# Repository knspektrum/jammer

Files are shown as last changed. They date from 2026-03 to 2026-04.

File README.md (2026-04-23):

# jammer

Milestones:
2026-04 - Finish research and ensure that everyone understands it.
2026-05 - Simulate core components. Complete simulation of both hardware and software (modulation/demodulation).
2026-06 - Order parts for the prototype like FPGA devboards.
2026-07 - Complete the prototype and develop software to jam things supported by the NRF jammer, implement signal reception and decoding.
2026-08 - Design the final PCB and place the order.

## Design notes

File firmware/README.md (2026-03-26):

NRF24L01+PA+LNA jammer for 2.4GHz band.

This project aims to create a jammer for devices operating in the [https://en.wikipedia.org/wiki/2.4_GHz_radio_use](2.4GHz band).

### Wiring
Check config.h. Currently we use 2 NRF modules, an SSD1306-compatible display (I2C), and 3 buttons for navigation.

### Theoretical basis
The NRF works on 2400-2525MHz frequencies. 1 channel = 1 MHz and there are 125 channels.

We can choose TX power and speed. Bandwidth depends on speed.
TX power: -18dBm, -12dBm, -6dBm, 0dBm
Speed: 1Mbps, 2Mbps, 250Kbps
Bandwidth: 1MHz or 2MHz

[https://docs.nordicsemi.com/bundle/nRF24L01P_PS_v1.0/resource/nRF24L01P_PS_v1.0.pdf](https://docs.nordicsemi.com/bundle/nRF24L01P_PS_v1.0/resource/nRF24L01P_PS_v1.0.pdf)

The status of RPD is correct when RX after an appropriate delay:
Tstby2a +Tdelay_AGC= 130us + 40us. RPD is used to detect activity on a band.

The RF channel frequency determines the center of the channel used by the nRF24L01+. The channel
occupies a bandwidth of less than 1MHz at 250kbps and 1Mbps and a bandwidth of less than 2MHz at
2Mbps. nRF24L01+ can operate on frequencies from 2.400GHz to 2.525GHz. The programming resolu-
tion of the RF channel frequency setting is 1MHz

build, upload and monitor:
make upload-release monitor

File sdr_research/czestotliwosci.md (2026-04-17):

# Częstotliwości

> Musimy doprecyzować jaki przedział częstotliwości nas interesuje, proponuję coś koło 20MHz-6GHz

125 kHz - jedna z częstotliwości RFID, zagłuszanie średnio ma sens ale można reply ataki robić i po prostu czytać dane
77.5 kHz - zegary atomowe, zagłuszanie może popsuć niektóre urządzenia które synchronizują się z nim, potencjlanie też można spoofować

13.56 MHz - kolejna częstotliwość RFID, tutaj wszystkie karty do hoteli, karty płatnicze, potencjlanie odczytywanie danych z nich
27 MHz - CB radio

87,5 do 108,0 MHz - pasmo dla radia FM, można zagłuszyć i nadawać swoje
108 – 137 MHz - pasma samolotów, można wyczytać lokalizacje
144.800 MHz - APRS, ludzie amatorsko reportują lokalizacje różnych obiektów, czasem ludzie tu wysyłają pogode albo wiadomości tekstowe
150.000 – 150.450 MHz - PKP tu nadaje, nieszyfrowana komunikacja, https://czestotliwosci.pl.tl/PKP.htm
161.975 / 162.025 - AIS, można słuchać gdzie statki pływają

433 MHz - legalne pasmo bez licencji, piloty do bram, kluczyki do samochodu
446,000 – 446,200 MHz - PMRy, "walkie talkie" ale używane też np na basenach przez ratowników
865–868 MHz - UHF RFID, używane w logistyce, jakieś paczki w magazynach
868 MHz - legalne pasmo, całe IoT z tego korzyta np lora. inteligentne liczniki gazu, prądu, wody, bezprzewodowe dzwonki
700 MHz – 2.6 GHz - całe GSM https://pl.wikipedia.org/wiki/Cz%C4%99stotliwo%C5%9Bci_u%C5%BCywane_w_sieci_GSM, obszerny temat
1575.42 MHz - GPS, da się spoofować
gnss - to całe pasmo do pozycji z satelit, dużo kraji ma swoje altenatywy do amerykańskiego GPS, Galileo OSNMA podpisuje swoje wiadomosci, uniemozliwia spoofowanie
2.4Ghz - wiadomo BT, BLE, WiFi, Zigbee, niektóre drony
5GHz, do 5875 MHz dokładnie - Kolejne pasmo wifi
5-6Ghz - FPV drony, https://oscarliang.com/fpv-channels/

Telewizja naziemna:
UHF (470-694 MHz, kanały 21-48) oraz VHF (174-230 MHz, kanały 6-12 dla MUX 8).

Około 145Mhz jest pasmo ISS (Międzynarodowa Stacja Kosmiczna)

Pasma SSTV, wysyłanie obrazów amatorsko:
3,735 MHz (3,730 MHz – 3,740 MHz)       LSB
7,165 MHz (7,035 MHz – 7,045 MHz)       LSB
14,230 MHz (14,225 MHz – 14,235 MHz)    USB
21,340 MHz (21,335 MHz – 21,345 MHz)    USB
28,680 MHz (28,675 MHz – 28,685 MHz)    USB
50,510 MHz      FM
144,500 MHz     FM
433,400 MHz     FM

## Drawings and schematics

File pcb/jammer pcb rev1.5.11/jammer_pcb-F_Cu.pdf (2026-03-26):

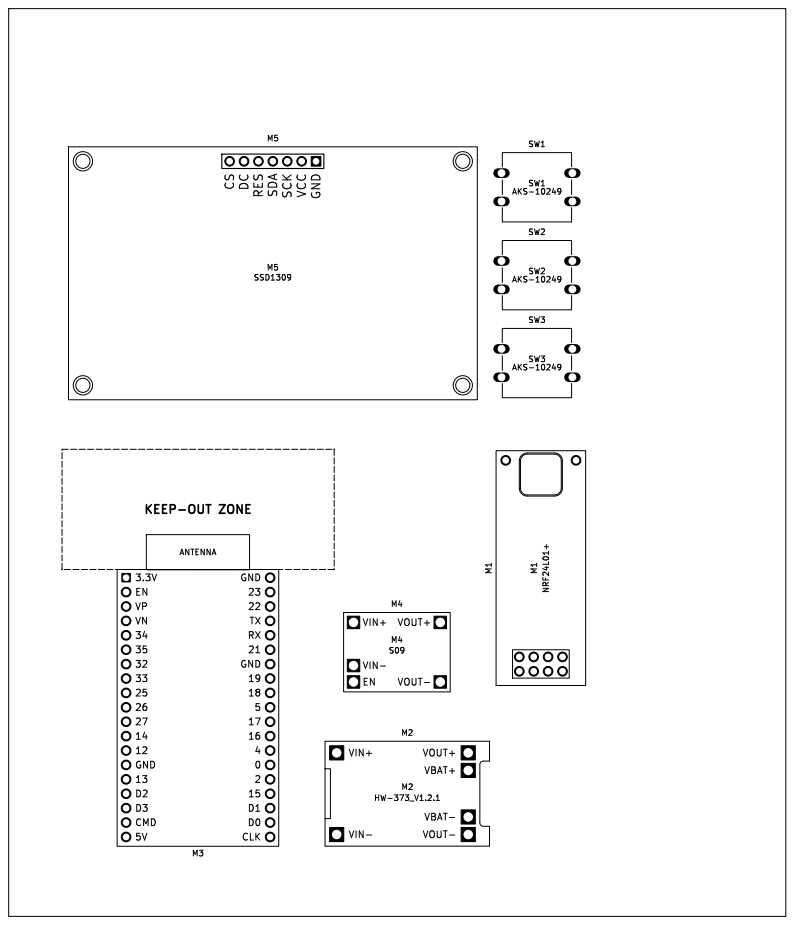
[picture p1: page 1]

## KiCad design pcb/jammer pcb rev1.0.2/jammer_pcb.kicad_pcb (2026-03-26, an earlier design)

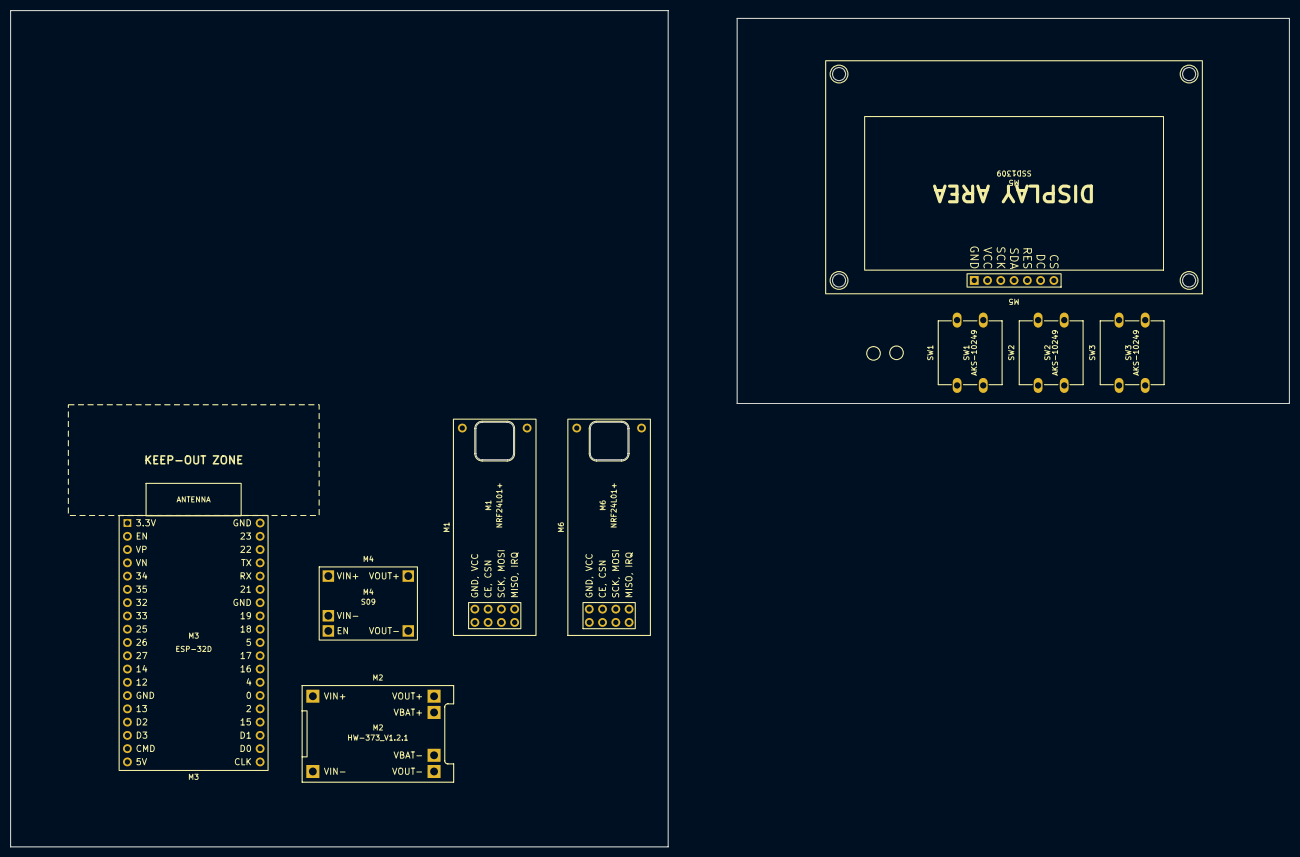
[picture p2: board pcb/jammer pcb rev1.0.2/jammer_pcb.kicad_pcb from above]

Board: 2 copper layers, 244.8 x 160.1 mm, 9 parts (0 on the bottom side), 3 nets, no tracks yet.

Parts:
M1, M6: NRF24L01+; Radio Module
M2: HW-373_V1.2.1; Battery Charger Layout
M3: ESP-32D; ESP32
M4: S09; Converter
M5: SSD1309; 2.42'' OLED Display Layout
SW1, SW2, SW3: AKS-10249; Button

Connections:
unnamed: SW1.1 (A), SW1.2 (A)
unnamed: SW2.1 (A), SW2.2 (A)
unnamed: SW3.1 (A), SW3.2 (A)

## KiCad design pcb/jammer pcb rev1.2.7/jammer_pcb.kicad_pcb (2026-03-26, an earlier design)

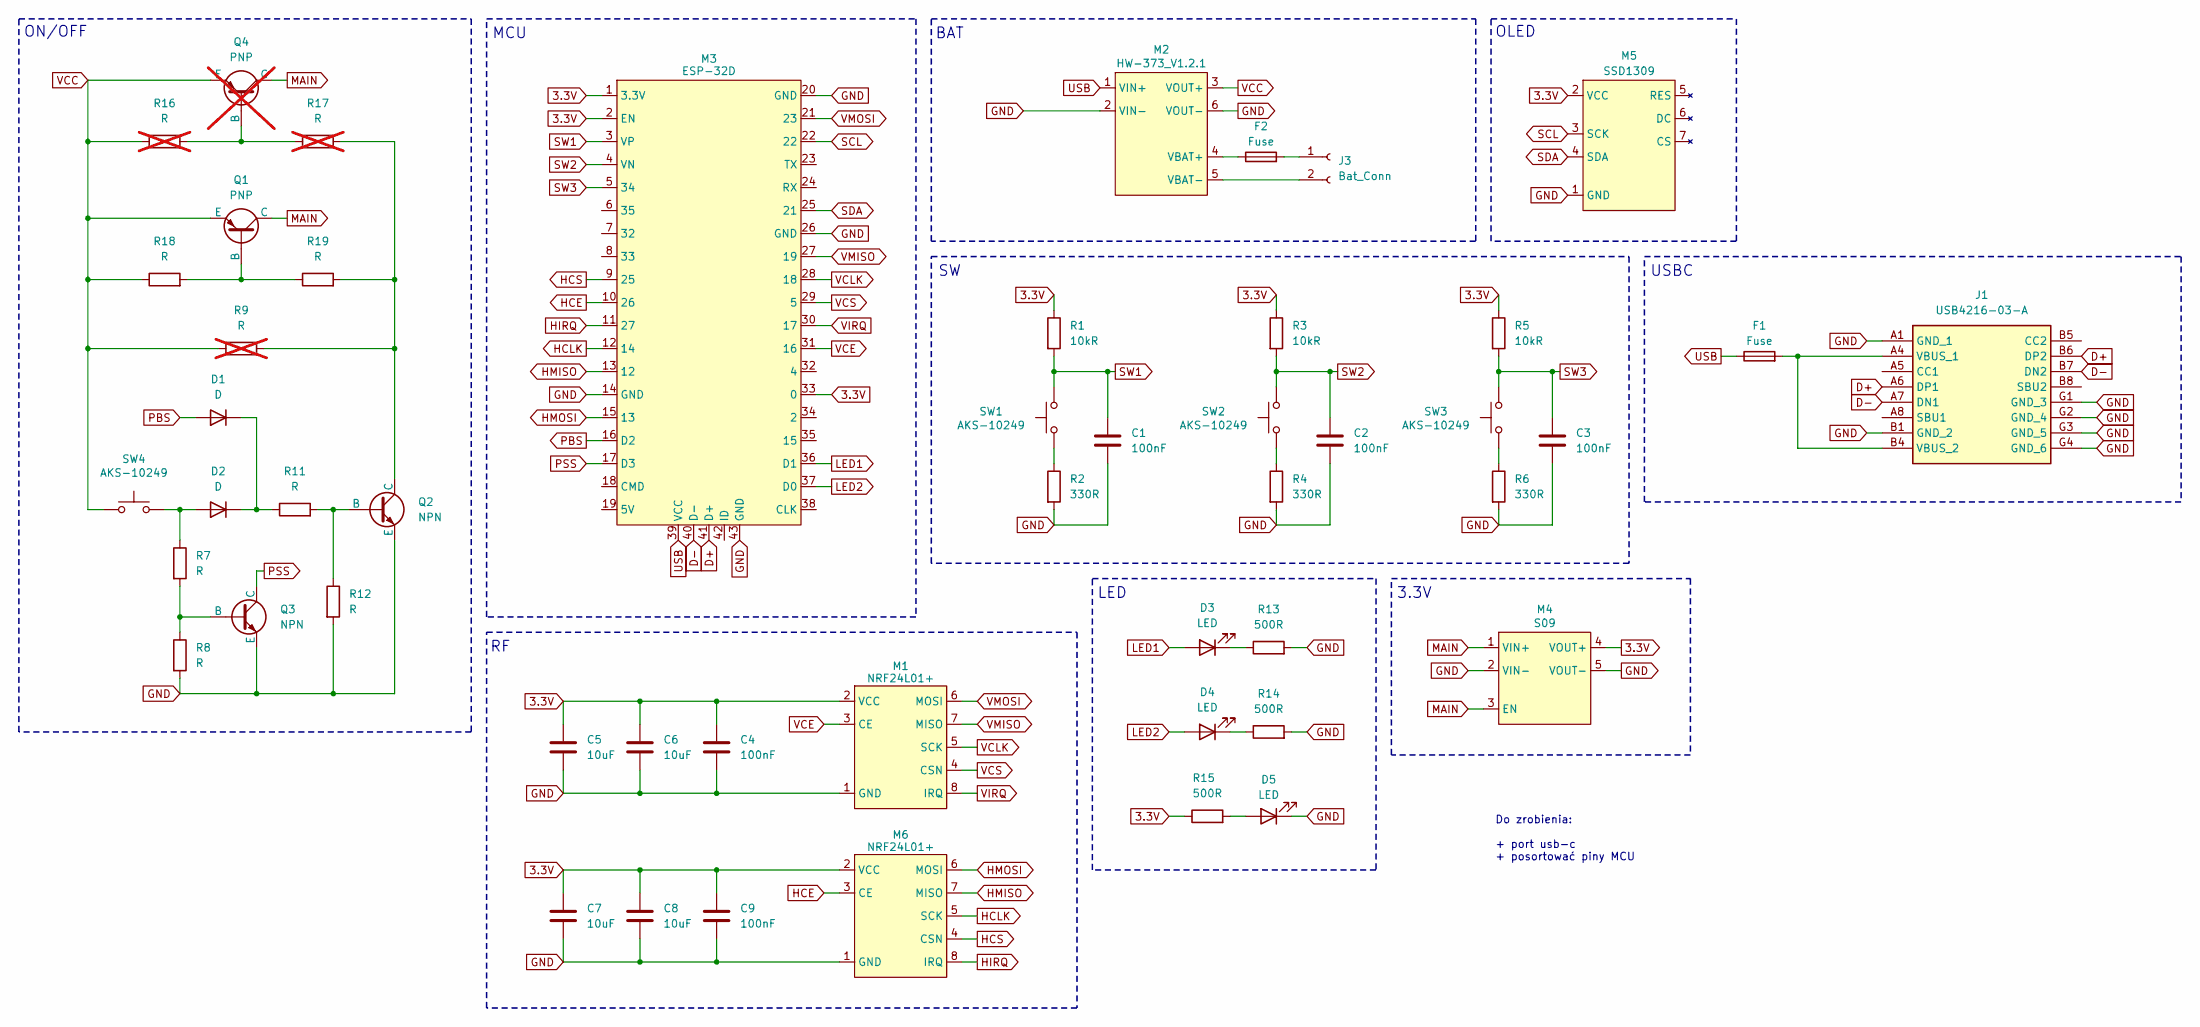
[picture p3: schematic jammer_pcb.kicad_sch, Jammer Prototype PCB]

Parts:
C1, C2, C3: 100nF; C_0603_1608Metric
C4, C9: 100nF; R_0805_2012Metric
C5, C6, C7, C8: 10uF; C_1206_3216Metric
D1, D2: D; D_SOD-323
D3, D4, D5: LED; D_0603_1608Metric
F1, F2: Fuse; R_1206_3216Metric
J1: USB4216-03-A; USB Port; Mouser Part Number 640-USB4216-03-A
J3: Bat_Conn; 2pin Socket
M1, M6: NRF24L01+; Radio Module
M2: HW-373_V1.2.1; Battery Charger Layout
M3: ESP-32D; ESP32
M4: S09; Converter
M5: SSD1309; 2.42'' OLED Displat Layout
Q1: PNP; SOT-89-3
Q2, Q3: NPN; SOT-23-3
Q4: PNP; SOT-89-3; not fitted
R1, R3, R5: 10kR; R_0603_1608Metric
R2, R4, R6: 330R; R_0603_1608Metric
R7, R8, R11, R12, R18, R19: R; R_0603_1608Metric
R9, R16, R17: R; R_0603_1608Metric; not fitted
R13, R14, R15: 500R; R_0603_1608Metric
SW1, SW2, SW3, SW4: AKS-10249; Button

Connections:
3.3V: C4.1, C5.1, C6.1, C7.1, C8.1, C9.1, M1.2 (VCC), M3.1 (3.3V), M3.2 (EN), M3.33 (0), M4.4 (VOUT+), M5.2 (VCC), M6.2 (VCC), R1.1, R3.1, R5.1, R15.1
D+: J1.A6 (DP1), J1.B6 (DP2), M3.41 (D+)
D-: J1.A7 (DN1), J1.B7 (DN2), M3.40 (D-)
GND: C1.2, C2.2, C3.2, C4.2, C5.2, C6.2, C7.2, C8.2, C9.2, D5.1 (K), J1.A1 (GND_1), J1.B1 (GND_2), J1.G1 (GND_3), J1.G2 (GND_4), J1.G3 (GND_5), J1.G4 (GND_6), M1.1 (GND), M2.2 (VIN-), M2.6 (VOUT-), M3.14 (GND), M3.20 (GND), M3.26 (GND), M3.43 (GND), M4.2 (VIN-), M4.5 (VOUT-), M5.1 (GND), M6.1 (GND), Q2.3 (E), Q3.3 (E), R2.2, R4.2, R6.2, R8.2, R12.2, R13.2, R14.2
HCE: M3.10 (26), M6.3 (CE)
HCLK: M3.12 (14), M6.5 (SCK)
HCS: M3.9 (25), M6.4 (CSN)
HIRQ: M3.11 (27), M6.8 (IRQ)
HMISO: M3.13 (12), M6.7 (MISO)
HMOSI: M3.15 (13), M6.6 (MOSI)
LED1: D3.2 (A), M3.36 (D1)
LED2: D4.2 (A), M3.37 (D0)
MAIN: M4.1 (VIN+), M4.3 (EN), Q1.2 (C), Q4.2 (C)
unnamed: D1.1 (K), D2.1 (K), R11.1
unnamed: D2.2 (A), R7.1, SW4.2 (B)
unnamed: D3.1 (K), R13.1
unnamed: D4.1 (K), R14.1
unnamed: D5.2 (A), R15.2
unnamed: F1.2, J1.A4 (VBUS_1), J1.B4 (VBUS_2)
unnamed: F2.2, J3.1
unnamed: J3.2, M2.5 (VBAT-)
unnamed: F2.1, M2.4 (VBAT+)
unnamed: Q1.1 (B), R18.2, R19.1
unnamed: Q2.1 (B), R11.2, R12.1
unnamed: Q2.2 (C), R9.2, R17.2, R19.2
unnamed: Q3.1 (B), R7.2, R8.1
unnamed: Q4.1 (B), R16.2, R17.1
unnamed: R2.1, SW1.1 (A)
unnamed: R4.1, SW2.1 (A)
unnamed: R6.1, SW3.1 (A)
PBS: D1.2 (A), M3.16 (D2)
PSS: M3.17 (D3), Q3.2 (C)
SCL: M3.22, M5.3 (SCK)
SDA: M3.25 (21), M5.4 (SDA)
SW1: C1.1, M3.3 (VP), R1.2, SW1.2 (B)
SW2: C2.1, M3.4 (VN), R3.2, SW2.2 (B)
SW3: C3.1, M3.5 (34), R5.2, SW3.2 (B)
USB: F1.1, M2.1 (VIN+), M3.39 (VCC)
VCC: M2.3 (VOUT+), Q1.3 (E), Q4.3 (E), R9.1, R16.1, R18.1, SW4.1 (A)
VCE: M1.3 (CE), M3.31 (16)
VCLK: M1.5 (SCK), M3.28 (18)
VCS: M1.4 (CSN), M3.29 (5)
VIRQ: M1.8 (IRQ), M3.30 (17)
VMISO: M1.7 (MISO), M3.27 (19)
VMOSI: M1.6 (MOSI), M3.21 (23)

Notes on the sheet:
3.3V
OLED
Do zrobienia: + port usb-c + posortować piny MCU
ON/OFF
BAT
USBC
MCU
LED

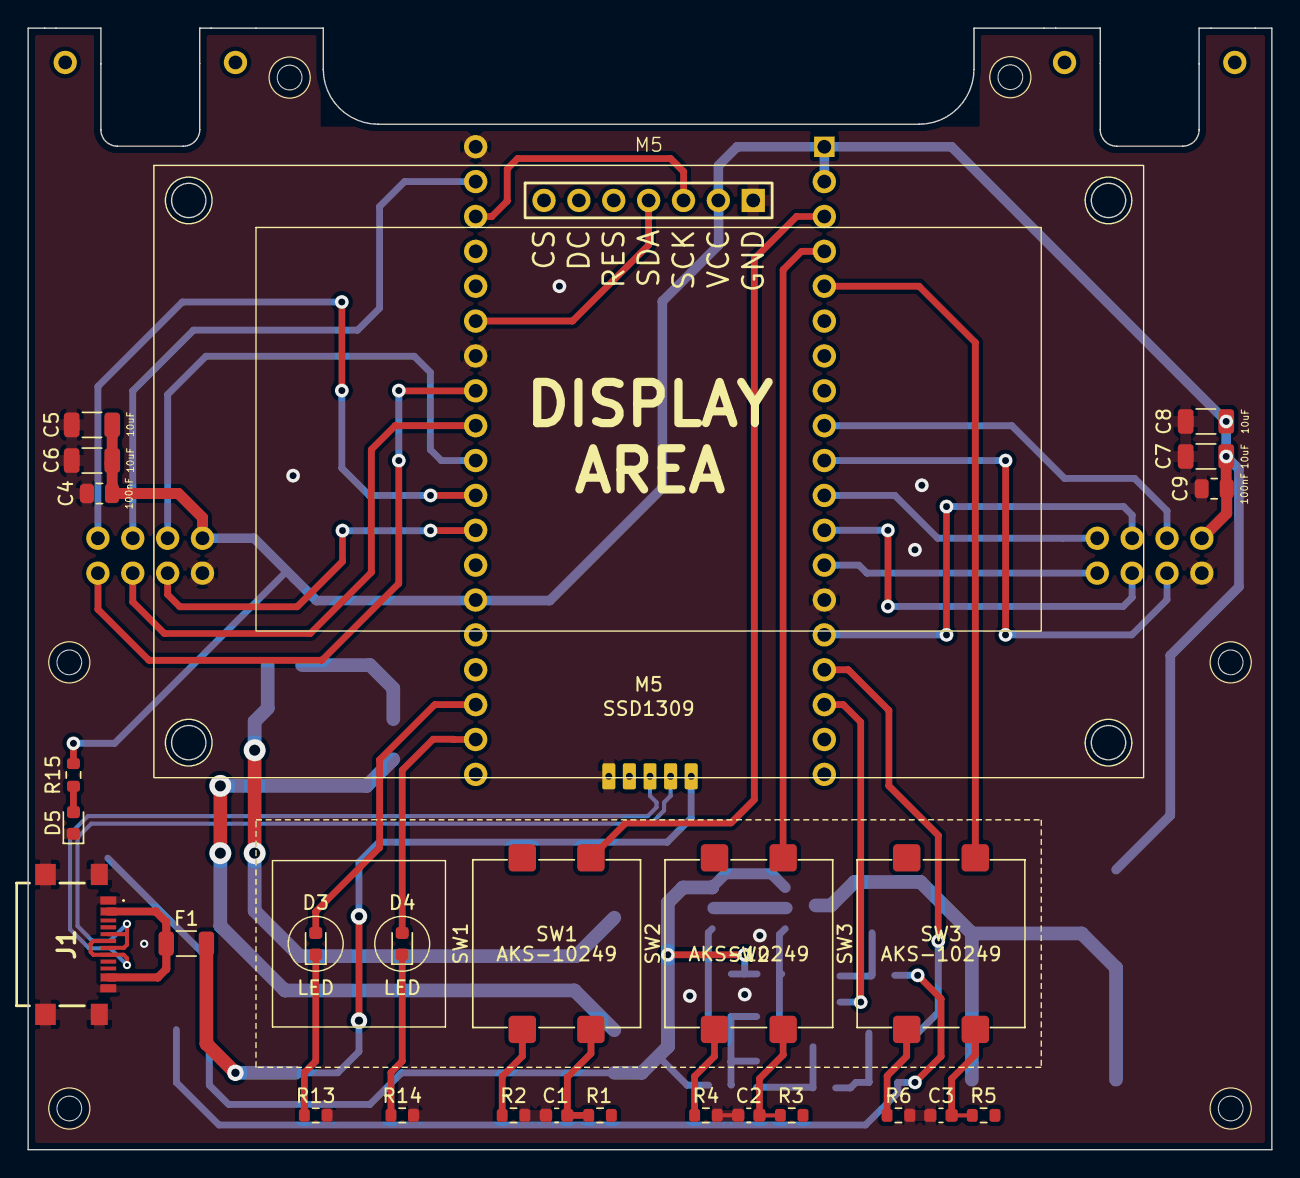
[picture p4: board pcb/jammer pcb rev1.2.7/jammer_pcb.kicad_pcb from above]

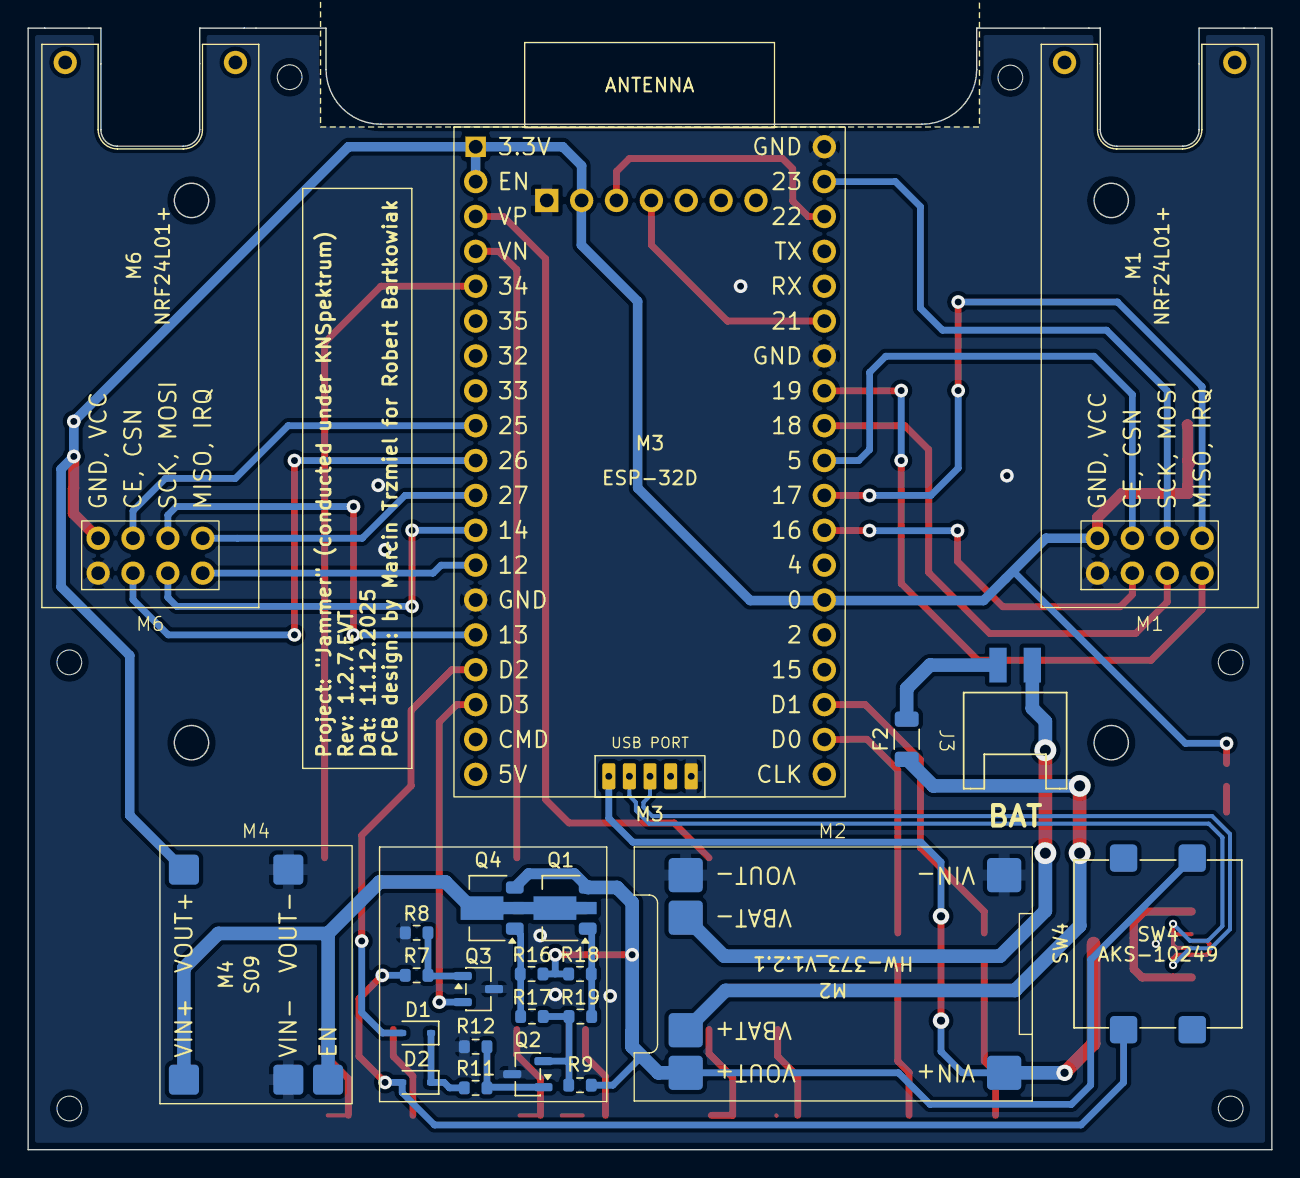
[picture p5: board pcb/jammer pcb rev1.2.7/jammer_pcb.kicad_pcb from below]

Board: 2 copper layers, 90.6 x 81.7 mm, 50 parts (23 on the bottom side), 45 nets.

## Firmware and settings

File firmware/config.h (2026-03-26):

#ifndef CONFIG_H
#define CONFIG_H

// general
#define DEFAULT_POWER 3
#define DEFAULT_CHANNEL 45
#define DEFAULT_SPEED 1

#define GAP 1
#define SPIKE_W 2

// nrf24l01
#define CHANNELS 126

// nrf1 is connected to vspi
#define NRF1_SPI VSPI
#define NRF1_MISO 19
#define NRF1_MOSI 23
#define NRF1_SCK 18
#define NRF1_CE 21
#define NRF1_CSN 22
// nrf2 is connected to hspi
#define NRF2_MISO 12
#define NRF2_MOSI 13
#define NRF2_SCK 14
#define NRF2_SPI HSPI
#define NRF2_CE 27
#define NRF2_CSN 26

// spectrum
#define SPECTRUM_X 0
#define SPECTRUM_Y (DISP_ROWS - SPECTRUM_H)
#define SPECTRUM_W DISP_COLS
#define SPECTRUM_H 18

// display
#define DISP_COLS 128
#define DISP_ROWS 64

#define I2C_ADDRESS_1 0x3C
#define I2C_ADDRESS_2 0x3D

#define I2C_SDA_PIN 17
#define I2C_SCL_PIN 5

// keyboard
#define EVENT_QUEUE_SIZE 32
#define LONG_PRESS_START_MS 600
#define LONG_PRESS_REPEAT_MS 200
#define DEBOUNCE_MS 25

#define KEY_LEFT 32
#define KEY_RIGHT 33
#define KEY_SELECT 25

#endif // !CONFIG_H

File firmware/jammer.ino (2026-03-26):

#include "HardwareSerial.h"
#include "config.h"
#include "jammer.h"
#include "kbd.h"
#include "nrfmods.h"
#include "scanner_page.h"
#include "settings_page.h"
#include "state.h"
#include "terminal.h"
#include "tx_page.h"
#include "wifi_scan_page.h"
#include <Arduino.h>

void setup() {
  Serial.begin(115200);
  Serial.println("nRF24L01 Channel Scanner and jammer");

  auto &kbd = Keyboard::instance();
  kbd.add_button(KEY_LEFT);
  kbd.add_button(KEY_RIGHT);
  kbd.add_button(KEY_SELECT);

  nrf_init();
  ScannerPage::instance()->init(&nrf1);
  Jammer::instance().init_radios(&nrf1, &nrf2);
  Terminal::instance().show_animation();
  Terminal::instance().get_page()->draw();
}

void loop() {
  auto &kbd = Keyboard::instance();

  kbd.update();

  InputEvent e;
  while (kbd.get_ev(&e)) {
    Terminal::instance().get_page()->handle_input(&e);
  }

  Terminal::instance().get_page()->update();
}

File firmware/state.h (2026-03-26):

#ifndef STATE_H
#define STATE_H

#include "config.h"
#include <cstddef>
#include <cstdint>

enum WiFiBandwidth : uint8_t { OFDM_20MHZ = 0, OFDM_40MHZ, DSSS_22MHZ, MAX };

struct GlobalSettings {
  // Set tx power : 0=-18dBm,1=-12dBm,2=-6dBm,3=0dBm
  static constexpr int8_t tx_power_to_dbm[] = {-18, -12, -6, 0};
  // 0=1Mbps, 1=2Mbps, 2=250Kbps
  static constexpr float tx_speed_to_mbps[] = {1, 2, 0.25};
  static constexpr uint8_t tx_speed_to_bw_mhz[] = {1, 2, 1};
  static constexpr uint8_t wifi_bandwidths[WiFiBandwidth::MAX] = {20, 22, 40};

  // 0=-18dBm,1=-12dBm,2=-6dBm,3=0dBm
  int tx_power = DEFAULT_POWER;
  // 0=1Mbps, 1=2Mbps, 2=250Kbps
  int tx_speed = DEFAULT_SPEED;
};

struct TxPageSettings {
  int mode = 0;
  // for wifi
  int wifi_channel = 1;
  int wifi_bandwidth = OFDM_20MHZ;
  // for range
  int range_start = 0;
  int range_end = 80;
  int range_step = 1;
};

class SystemState {
public:
  GlobalSettings global;
  TxPageSettings tx_page;

  static SystemState &instance() {
    static SystemState ss;
    return ss;
  }
};

#endif
